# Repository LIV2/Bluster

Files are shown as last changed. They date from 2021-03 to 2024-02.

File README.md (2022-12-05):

# Bluster - A2000 CPLD Buster replacment
This is a replacement for the Buster IC used in the Amiga 2000

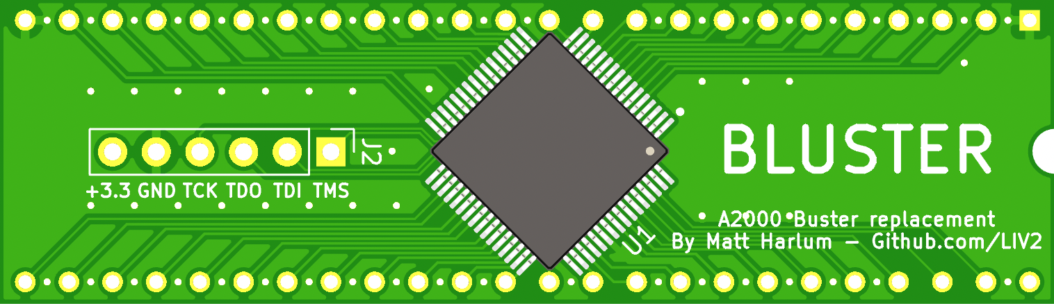
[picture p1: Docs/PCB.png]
PCB


## Programming the CPLD
Download the firmware corresponding to your board revision (right-click -> save as):

* [Rev A](https://github.com/LIV2/Bluster/raw/master/Binary/Bluster_rev_a.jed)
* [Rev B](https://github.com/LIV2/Bluster/raw/master/Binary/Bluster_rev_b.jed)
* [Rev C](https://github.com/LIV2/Bluster/raw/master/Binary/Bluster_rev_c.jed)

And follow the instructions found [Here](Programming.md)

## Revision History
So far there are no functional differences across the various revisions, just rerouting, pin swapping and part changes
 
* Rev A: Initial Revision
* Rev B: Design into smaller PCB
* Rev C: Tweak PCB design, change LDO to more standard LM1117 type

## Bill of materials
Make sure to use the BOM that matches the revision of your Bluster PCB.

* [Rev A/B BOM](BOM_rev_ab.md)
* [Rev C BOM](BOM_rev_c.md)

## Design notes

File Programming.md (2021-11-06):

# Programming XC95xxXL CPLD's with Raspberry Pi

Programming the CPLD from a Raspberry Pi is easy thanks to a tool called xc3sprog just follow the simple steps below and you'll be done in no time!

## Install xc3sprog

```shell
# Add Repo
curl -L https://apt.matrix.one/doc/apt-key.gpg | sudo apt-key add -
echo "deb https://apt.matrix.one/raspbian $(lsb_release -sc) main" | sudo tee /etc/apt/sources.list.d/matrixlabs.list

# Install
sudo apt-get update
sudo apt install matrixio-xc3sprog
```

## Connect RPi to JTAG header

While you can power the target from the Raspberry Pi's 3v pin I'd recommend you instead power the board by installing it in your Amiga and having it powered while programming.  
Make the following connections from your RPi:  
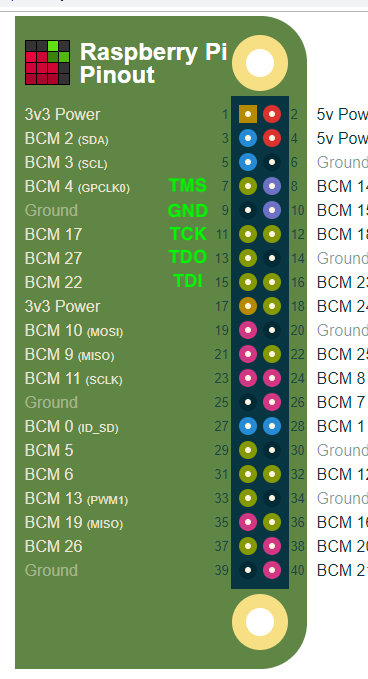
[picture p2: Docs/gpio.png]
PCB


|Pin|Signal|
|---|---|
|7|TMS|
|11|TCK|
|13|TDO|
|15|TDI|
|9|GND|

## Program

```
sudo xc3sprog -c sysfsgpio_creator -p 0 -v Buster.jed
```

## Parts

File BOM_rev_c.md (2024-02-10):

|Component|Location|QTY|Link|
|---|---|---|---|
|XC9572XL-10VQ64C|U1|1|[Mouser](https://www.mouser.se/ProductDetail/217-C9572XL-10VQG64C)|
|LM1117-3.3|U2|1|[Mouser](https://www.mouser.com/ProductDetail/863-NCP1117ST33T3G)|
|0.1uF Ceramic Capacitor, 0805|C1-4|4|[Mouser](https://www.mouser.com/ProductDetail/963-EMF212B7104MGHT)|
|10uF Ceramic Capacitor, 0805|C5,C6|2|[Mouser](https://www.mouser.com/ProductDetail/187-CL21A106KOQNNNG)|

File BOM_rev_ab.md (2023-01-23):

|Component|Location|QTY|Link|
|---|---|---|---|
|XC9572XL-10VQ64C|U1|1|[Mouser](https://www.mouser.se/ProductDetail/217-C9572XL-10VQG64C)|
|TC1262-3.3|U2|1|[Mouser](https://www.mouser.com/ProductDetail/579-TC1262-3.3VDB)|
|0.1uF Ceramic Capacitor, 0805|C1-4|4|[Mouser](https://www.mouser.com/ProductDetail/963-EMF212B7104MGHT)|
|10uF Ceramic Capacitor, 0805|C5,C6|2|[Mouser](https://www.mouser.com/ProductDetail/187-CL21A106KOQNNNG)|

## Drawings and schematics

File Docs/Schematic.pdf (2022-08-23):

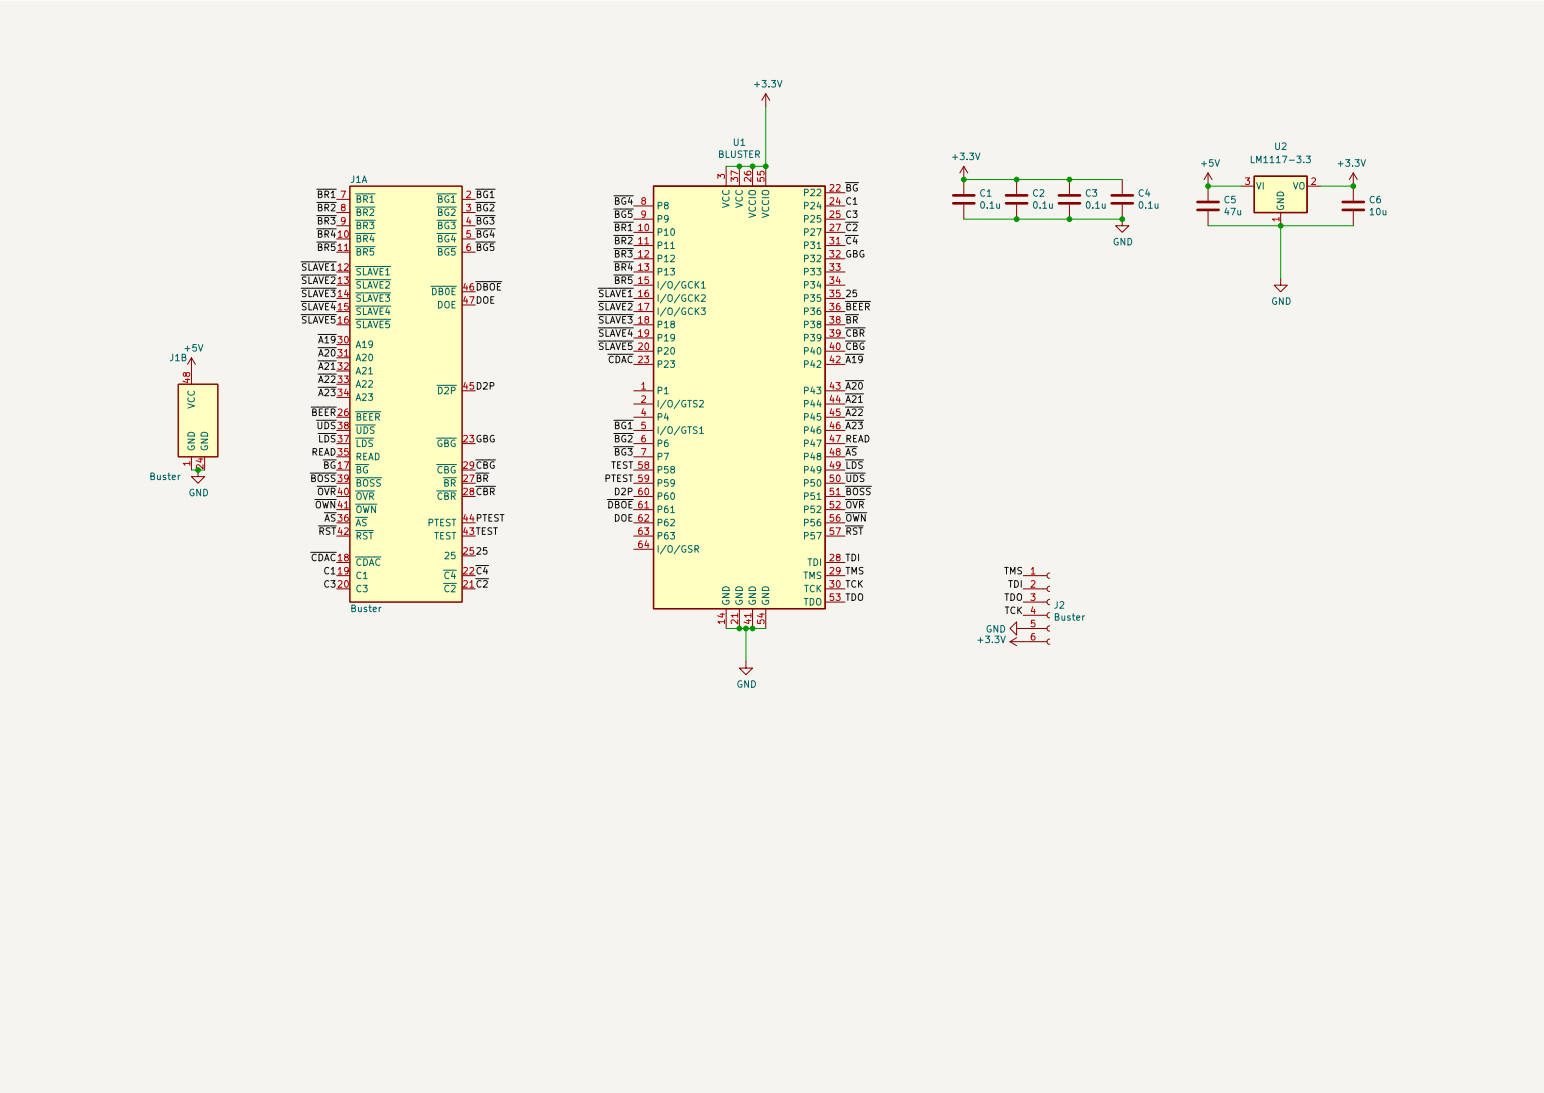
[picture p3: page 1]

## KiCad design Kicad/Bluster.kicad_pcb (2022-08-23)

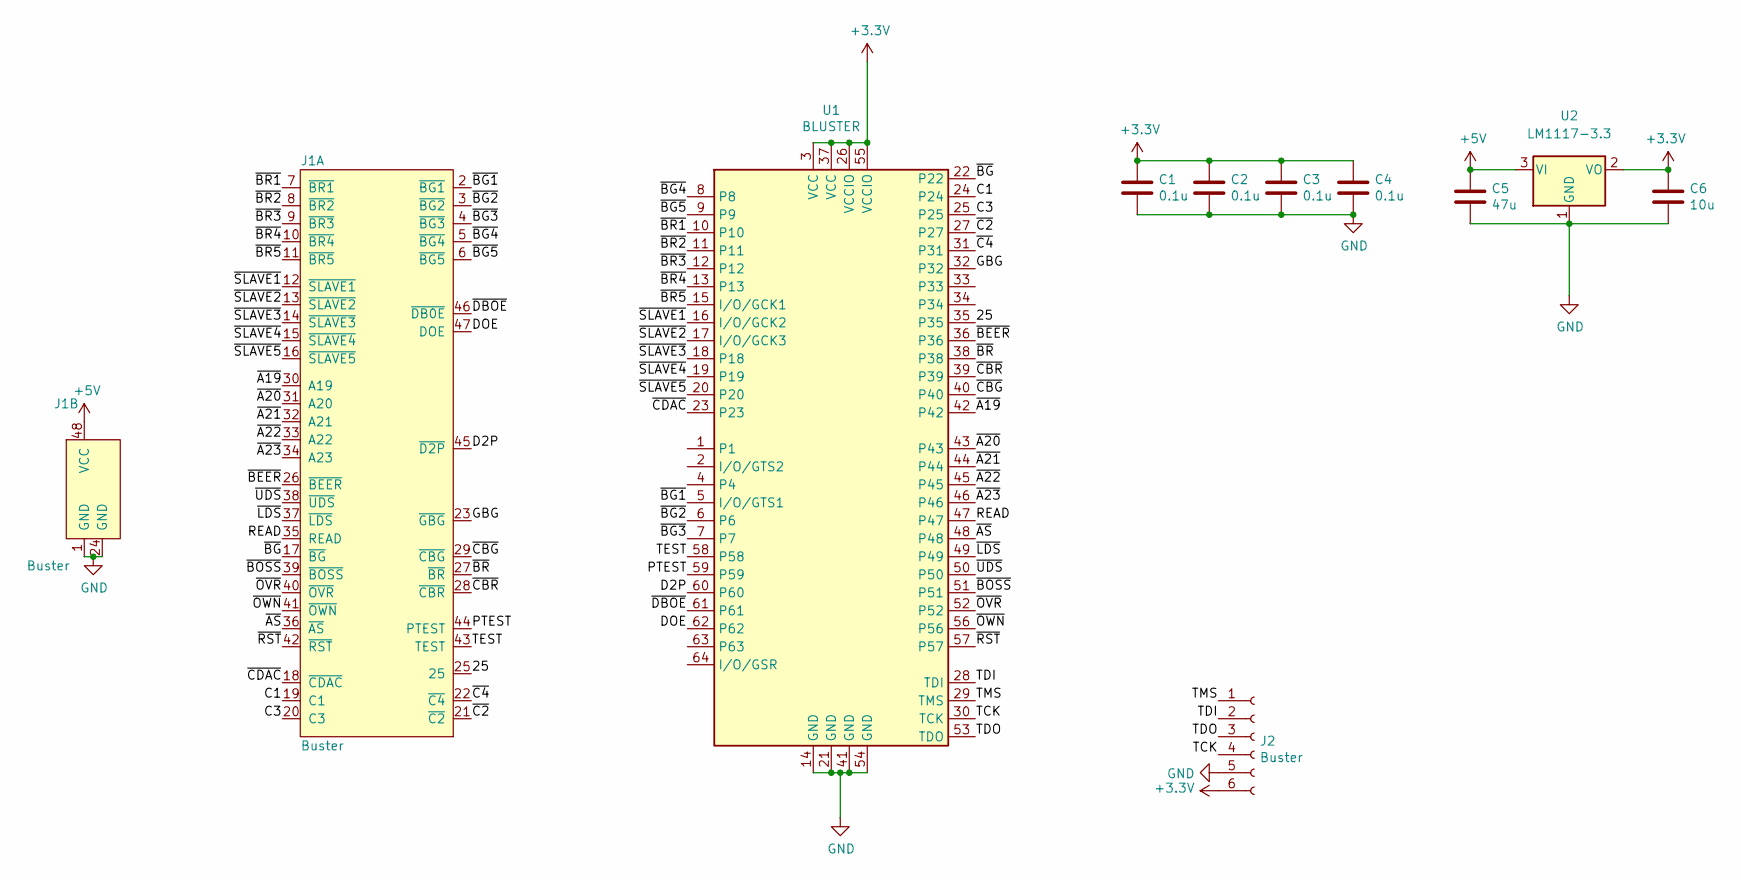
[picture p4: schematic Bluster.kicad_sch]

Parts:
C1, C2, C3, C4: 0.1u; C_0805_2012Metric_Pad1.18x1.45mm_HandSolder
C5: 47u; C_0805_2012Metric_Pad1.18x1.45mm_HandSolder
C6: 10u; C_0805_2012Metric_Pad1.18x1.45mm_HandSolder
J1: Buster; DIP-48_W15.24mm_Socket
J2: Buster; PinHeader_1x06_P2.54mm_Vertical
U1: BLUSTER; TQFP-64_10x10mm_P0.5mm
U2: LM1117-3.3; SOT-223-3_TabPin2

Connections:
+3V3: C1.1, C2.1, C3.1, C4.1, C6.1, J2.6, U1.3 (VCC), U1.26 (VCCIO), U1.37 (VCC), U1.55 (VCCIO), U2.2 (VO)
+5V: C5.1, J1.48 (VCC), U2.3 (VI)
/25: J1.25, U1.35
/C1: J1.19 (C1), U1.24
/C3: J1.20 (C3), U1.25
/D2P: J1.45 (~D2P), U1.60
/DOE: J1.47 (DOE), U1.62
/GBG: J1.23 (~GBG), U1.32
/PTEST: J1.44 (PTEST), U1.59
/READ: J1.35 (READ), U1.47
/TCK: J2.4, U1.30 (TCK)
/TDI: J2.2, U1.28 (TDI)
/TDO: J2.3, U1.53 (TDO)
/TEST: J1.43 (TEST), U1.58
/TMS: J2.1, U1.29 (TMS)
/~A19: J1.30 (A19), U1.42
/~A20: J1.31 (A20), U1.43
/~A21: J1.32 (A21), U1.44
/~A22: J1.33 (A22), U1.45
/~A23: J1.34 (A23), U1.46
/~AS: J1.36 (~AS), U1.48
/~BEER: J1.26 (~BEER), U1.36
/~BG1: J1.2 (~BG1), U1.5 (I/O/GTS1)
/~BG2: J1.3 (~BG2), U1.6
/~BG3: J1.4 (~BG3), U1.7
/~BG4: J1.5 (~BG4), U1.8
/~BG5: J1.6 (~BG5), U1.9
/~BG: J1.17 (~BG), U1.22
/~BOSS: J1.39 (~BOSS), U1.51
/~BR1: J1.7 (~BR1), U1.10
/~BR2: J1.8 (~BR2), U1.11
/~BR3: J1.9 (~BR3), U1.12
/~BR4: J1.10 (~BR4), U1.13
/~BR5: J1.11 (~BR5), U1.15 (I/O/GCK1)
/~BR: J1.27 (~BR), U1.38
/~C2: J1.21 (~C2), U1.27
/~C4: J1.22 (~C4), U1.31
/~CBG: J1.29 (~CBG), U1.40
/~CBR: J1.28 (~CBR), U1.39
/~CDAC: J1.18 (~CDAC), U1.23
/~DBOE: J1.46 (~DB0E), U1.61
/~LDS: J1.37 (~LDS), U1.49
/~OVR: J1.40 (~OVR), U1.52
/~OWN: J1.41 (~OWN), U1.56
/~RST: J1.42 (~RST), U1.57
/~SLAVE1: J1.12 (~SLAVE1), U1.16 (I/O/GCK2)
/~SLAVE2: J1.13 (~SLAVE2), U1.17 (I/O/GCK3)
/~SLAVE3: J1.14 (~SLAVE3), U1.18
/~SLAVE4: J1.15 (~SLAVE4), U1.19
/~SLAVE5: J1.16 (~SLAVE5), U1.20
/~UDS: J1.38 (~UDS), U1.50
GND: C1.2, C2.2, C3.2, C4.2, C5.2, C6.2, J1.1 (GND), J1.24 (GND), J2.5, U1.14 (GND), U1.21 (GND), U1.41 (GND), U1.54 (GND), U2.1 (GND)

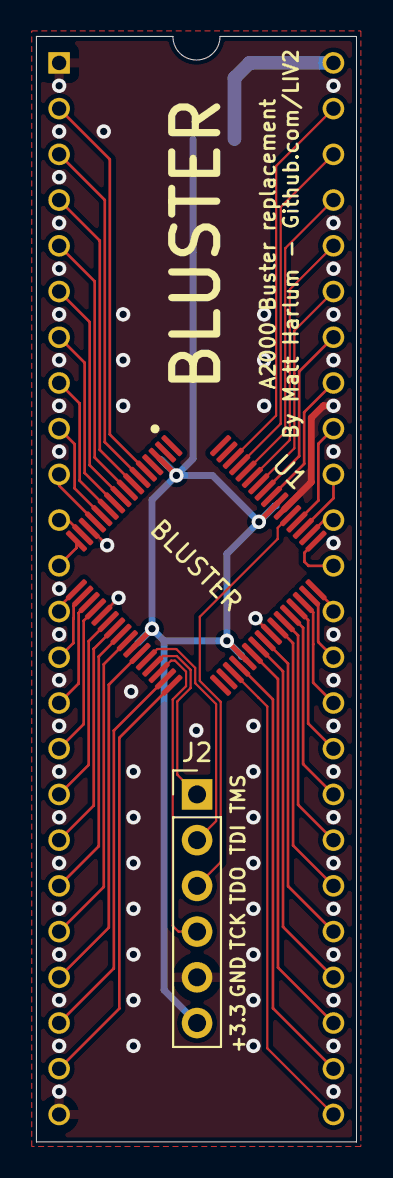
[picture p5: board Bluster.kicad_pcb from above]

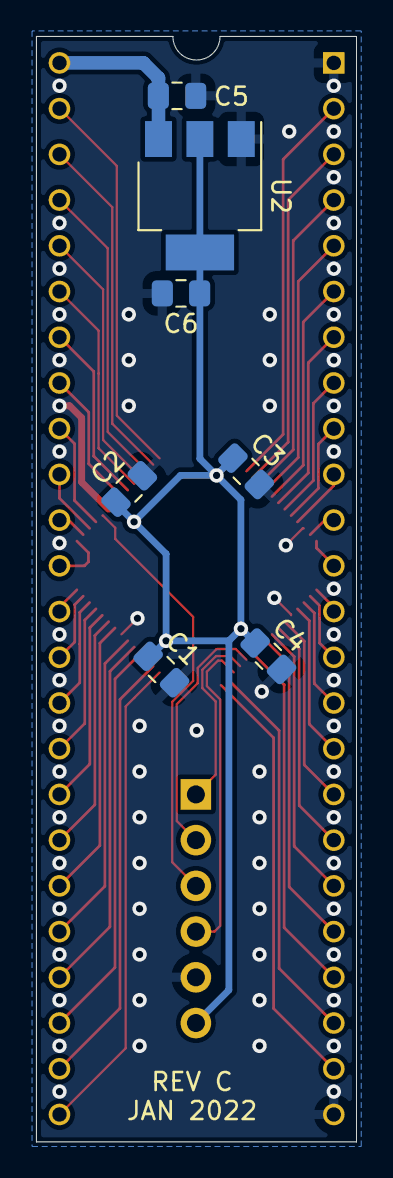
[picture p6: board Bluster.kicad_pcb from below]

Board: 2 copper layers, 17.8 x 61.4 mm, 10 parts (7 on the bottom side), 52 nets.

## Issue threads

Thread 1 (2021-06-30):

Perhaps possible to reduce size of PCB

niklasekstrom, 2021-06-30:
The other day I was playing around with placing an XC9572XL-10VQ64C in between the rows of a DIP40 socket, and ended up with something like this:

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

Not sure if it could work for your Bluster design, but if possible it could reduce the size of the PCB a little.

LIV2, 2021-07-01:
Thanks, I should probably do that - the current design I did was pure laziness and wanting to get something I could test quickly but it could be smaller :)

Great work with the Verilog CIA implementation btw!

Closed 2021-10-06.

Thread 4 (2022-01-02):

Change LDO footprint

LIV2, 2022-01-02:
Change the LDO footprint to be the standard LM1117 footprint.
I made a mistake choosing the TC1262 which as a different footprint to the LM1117.

LIV2, 2022-01-16:
Done in 6e7bdd0732e0d53e35c4098cca269dc83c646402

Closed 2022-11-19.

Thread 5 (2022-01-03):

Reuse board for Gary replacement

niklasekstrom, 2022-01-03:
By routing pins 25, 43, and 44 on the 48-pin DIP socket to free pins on the CPLD, it is possible to reuse the PCB to replace the Gary chip in an A500, using a different RTL.

LIV2, 2022-01-03:
I forgot about this. I will do this soon :)

LIV2, 2022-01-16:
@niklasekstrom I have routed these extra pins now in the rev_c branch. I will merge to master after testing the new board

LIV2, 2022-11-19:
Merged Rev C a while ago :)

Closed 2022-11-19.

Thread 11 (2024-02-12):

Possible improvements

furrtek, 2024-02-12:
Hello,

I just finished reverse-engineering a silicon die shot of BUSTER.
There are a few discrepancies between the extracted schematics and your verilog code.
I'm not familiar with the Amiga so I can't really tell if those are from modifications needed for the CPLD to work, or consequences of guessing the logic by observing the signals ?

https://github.com/furrtek/SiliconRE/tree/master/Commodore/CSG5721

LIV2, 2024-02-12:
Hi @furrtek!

The logic was written based off observed behaviour and based on the pal equations from the German A2000 which was pre-Buster

It's great to see the reverse engineered schematics! I will study them and correct the Bluster logic to match soon. (I recently moved countries and my Amigas are still in transit)

LIV2, 2024-02-12:
After looking for a bit I've already noticed some small differences that will be easy for me to fix, and one expected deviation that is needed due to the faster timing of the CPLD.

1. Chipram address should go up to $1FFFFF
2. Reserved range should start at $B80000 not $A00000
https://github.com/LIV2/Bluster/blob/d5636e67cf82da5e60242252896920507d89563d/RTL/Bluster.v#L76-L77

3. Collision circuit doesn't work as expected, XORing all inputs will not have the desired result (i.e an odd number of SLAVEs would not trigger a collision)
https://github.com/LIV2/Bluster/blob/d5636e67cf82da5e60242252896920507d89563d/RTL/Bluster.v#L84

4. DOE hack - An expected deviation from original - ASn buffered as DASn to deal with different timings of CPLD
https://github.com/LIV2/Bluster/blob/d5636e67cf82da5e60242252896920507d89563d/RTL/Bluster.v#L90-L92

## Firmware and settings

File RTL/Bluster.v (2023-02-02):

/*

BUSTIN' MAKES ME FEEL GOOD!

Bluster - CPLD Replacement for Amiga 2000's Buster
Copyright 2021 Matthew Harlum

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
*/

//`define badbuster // Emulate 1st rev of Buster that had a bug requiring buster tower

module Bluster(
  input [5:1] BR,
  input [5:1] SLV,
  input [23:19] ADDR,
  input UDSn,
  input LDSn,
  input READ,
  input BGn,
  input BOSSn,
  input OVRn,
  input OWNn,
  input ASn,
  input RESETn,
  input CDACn,
  input C1,
  input C3,
  inout BEERn,
  inout CBRn,
  inout CBGn,
  output DOE,
  output DBOEn,
  output D2Pn,
  output GBGn,
  output reg BRn,
  output reg [5:1] BG,
  output reg C4n,
  output reg C2n
  );

// Clocks
wire C7M;

assign C7M = !(C1 ^ C3);

always @(posedge CDACn)
begin
  C2n <= !C1;
end

always @(negedge CDACn)
begin
  C4n <= !C3;
end

// Collision
wire nocollision;
wire mainboard;

// Reserved address ranges
// Buster triggers a bus error if a PIC answers to these addresses (unless it asserts OVR)
assign mainboard = (
  ADDR[23:21] == 3'b000   |  // $000000-0FFFFF - Chip RAM
  ADDR[23:21] == 3'b101   |  // $A00000-BFFFFF - RESERVED
  ADDR[23:21] == 3'b110   |  // $C00000-DFFFFF - Pseudo-Fast RAM
  ADDR[23:19] == 5'b11100 |  // $E00000-E7FFFF - RESERVED
  ADDR[23:19] == 5'b11111    // $F80000-FFFFFF - Kickstart ROM
  ) & !ASn & RESETn & OVRn;

// If more than one PIC answers at the same time throw a bus error.
assign nocollision = (!SLV[5] ^ !SLV[4] ^ !SLV[3] ^ !SLV[2] ^ !SLV[1] ^ mainboard) | (SLV[5] & SLV[4] & SLV[3] & SLV[2] & SLV[1] & !mainboard);
assign BEERn = (!nocollision & RESETn) ? 1'b0 : 1'bZ;

/// Steering


// Dirty hack
// Add a delay to ASn so that DBOE/DOE are held a little longer into S7
(*KEEP = "true" *) BUF ASn_buf1 (.I(ASn),.O(DASn));

// Delayed ASn needed for buffer control and DOE
// Based on the circuitry of the German A2000
// ASn/DOE/DBOE Delayed until we're in the correct phase with the custom chips

reg ASnd1; // ASn delayed until C2
reg ASnd2; // ASnd1 delayed until C7M


//always @(negedge C2n or posedge ASn)
always @(negedge C2n or posedge DASn)
begin
  if (DASn) begin
    ASnd1 <= 1;
  end else begin
    ASnd1 <= ASn;
  end
end

always @(posedge C7M or posedge DASn)
begin
  if (DASn) begin
    ASnd2 <= 1;
  end else begin
    ASnd2 <= ASnd1;
  end
end

assign DOE = !ASnd2;

// Data buffer direction control
assign D2Pn = !(
  OWNn & READ & (!SLV[1]|!SLV[2]|!SLV[3]|!SLV[4]|!SLV[5])    | // CPU reading from Zorro card
  !OWNn & !READ & SLV[1] & SLV[2] & SLV[3] & SLV[4] & SLV[5] // Zorro master writing to mainboard
`ifndef badbuster
  | !OWNn & (!SLV[1] | !SLV[2] | !SLV[3] | !SLV[4] | !SLV[5])    // Zorro to Zorro 
`endif
);

// Need to double-check this against real Buster, initial look seems to always enable the buffer for every access. need to confirm...
// Data buffer output enable
assign DBOEn = !(
/*  // Based on pal equations in A500/2000 TRM
  !ASn & !READ & BEERn & OWNn                                                              | // CPU writing to Zorro
  (!UDSn|!LDSn) & READ & !ASnd2 & BEERn & OWNn                                              | // CPU reading from Zorro
  !ASn & !READ & BEERn & !OWNn & SLV[1] & SLV[2] & SLV[3] & SLV[4] & SLV[5]                | // Zorro DMA to mainboard
  (!UDSn|!LDSn) & READ & !ASnd2 & BEERn & !OWNn & SLV[1] & SLV[2] & SLV[3] & SLV[4] & SLV[5]  // Zorro DMA from mainboard
*/
  // Observed behavior on Rev 4.4 B2000
  !DASn & !READ & BEERn
  | (!UDSn|!LDSn) & READ & !ASnd2 & BEERn   
);



// Arbitration

reg BGOLDn;
reg COPBG;
wire BGRANT;

// If BOSS asserted, switch the direction of CBG and CBR
//
// When BOSSn is not true (68K owns the bus)
//   CBR is an input  - Coprocessor signals it's bus request to Buster
//   CBG is an output - Buster signals the bus grant back to the Coprocessor
//
// When BOSSn is true (Copro has taken over)
//   CBR is an output - Bus requests are sent to the Coprocessor
//   CBG is an input  - Coprocessor signals the bus grant to Buster
//
//
assign CBGn = (BOSSn) ? COPBG : 1'bZ;
assign CBRn = (!BOSSn) ? BRn  : 1'bZ;

assign BGRANT = (BOSSn) ? BGn : CBGn;
assign GBGn   = (BOSSn) ? BGn : CBGn;


always @(posedge C7M)
begin
  BGOLDn <= BGRANT; // Store old state of BG
  
  // Generate requests & hold grants
  // Coprocessor has highest priority
  COPBG = !(( RESETn & !BGRANT & BGOLDn & BOSSn & !CBRn ) | (RESETn & !BGn & !COPBG));
  BG[1] = !(( RESETn & !BGRANT & BGOLDn & (CBRn | !BOSSn) & !BR[1] ) | (RESETn & !BGRANT & !BG[1]));
  BG[2] = !(( RESETn & !BGRANT & BGOLDn & (CBRn | !BOSSn) & BR[1] & !BR[2] ) | (RESETn & !BGRANT & !BG[2]));
  BG[3] = !(( RESETn & !BGRANT & BGOLDn & (CBRn | !BOSSn) & BR[1] & BR[2] & !BR[3] ) | (RESETn & !BGRANT & !BG[3]));
  BG[4] = !(( RESETn & !BGRANT & BGOLDn & (CBRn | !BOSSn) & BR[1] & BR[2] & BR[3] & !BR[4] ) | (RESETn & !BGRANT & !BG[4]));
  BG[5] = !(( RESETn & !BGRANT & BGOLDn & (CBRn | !BOSSn) & BR[1] & BR[2] & BR[3] & BR[4] & !BR[5] ) | (RESETn & !BGRANT & !BG[5]));
 
  BRn <= (!RESETn | ((CBRn | !BOSSn) & BR[1] & BR[2] & BR[3] & BR[4] & BR[5]));
end
endmodule

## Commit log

2021-02-13 Initial commit.
    [Bluster-B_Cu.gbr, Bluster-B_Mask.gbr, Bluster-B_Paste.gbr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]
2021-10-06 Re-do PCB to fit within standard DIP footprint
    Fixes #1
    [Bluster-B_Cu.gbr, Bluster-B_Mask.gbr, Bluster-B_Paste.gbr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]
2021-10-10 It helps to update the schematic...
2022-01-02 Tweak DBOE/DOE timings to try and match the timings of a real buster
    * Delay DBOE/DOE slightly
    * Change compile time option "slew" to slow fixing a DBOE glitch
    [Bluster.v]
2022-06-10 Fix-up incorrect Gerbers in repo
    [Bluster-B_Cu.gbr, Bluster-B_Mask.gbr, Bluster-B_Paste.gbr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]
2022-08-23 Rev C
    * Change LDO to LM1117
    * Route extra pins to allow use for Gary
    [Bluster-B_Cu.gbr, Bluster-B_Mask.gbr, Bluster-B_Paste.gbr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]
2022-08-23 It helps to publish the gerbers...
    [Bluster-B_Cu.gbr, Bluster-B_Mask.gbr, Bluster-B_Paste.gbr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]
2022-08-23 It helps to regenerate gerbers...
    [Bluster-B_Cu.gbr, Bluster-B_Mask.gbr, Bluster-B_Paste.gbr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]
2022-08-23 Fixup TDI trace which stuck out to the side of the pad
    [Bluster-B_Cu.gbr, Bluster-B_Mask.gbr, Bluster-B_Paste.gbr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]
2023-01-23 Update BOMs, C5 can be 10uF to simplify the BOM
2023-02-02 Update comments for bus grant circuit
2024-02-10 Update BOM_rev_c.md
    Corrected the quantity for the 10uF cap in the rev C BOM

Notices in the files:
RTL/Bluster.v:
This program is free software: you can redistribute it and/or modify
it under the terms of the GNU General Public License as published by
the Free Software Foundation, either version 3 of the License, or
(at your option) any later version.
